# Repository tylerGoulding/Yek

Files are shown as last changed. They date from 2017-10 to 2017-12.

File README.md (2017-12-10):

# YEK
Yek is a prototype of an on-hand password manager that redefines how users interact with account safety and passwords on a laptop computer. It is an embedded device that acts as your personal butler to memorize passwords. With a yek device and a fingerprint scan, you can login to any of your accounts by connecting to any computer device through a bluetooth connection. Yek  acts as a keyboard and types in your login information (username and password) to the selected textbox of a login page, so that you do not have to remember your unique and strong passwords. It can fit in your pocket just like a physical keychain, and yet it can hold 63 of your accounts through a computer application.

## Team
- Fatema Almeshqab
- Tyler Goulding
- Matt Chu

## Code
When prototyping, we developed in Arduino then ported it to AVR C. We have included both for your convenience.

## PCB
The pcb was designed in Eagle. There is one error in the PCB if you are planning to send it out (or printing it in house if that's your slice of pie). The pins on the Battery JST plug are flipped. This is not a major issue but change it if you would like. We did not so that the professors could see our the equivalent PCB we printed.
## Computer Application
The computer application was written in Java and is available as a runnable .jar file that works on Windows, Mac, or Linux, and just requires that Java 8 be installed. The app, uses a library called jSerialComm to communicate with the Yek through a serial port connection.

## Building the Yek
### If you want to use Arduino
To build with Arduino:
Download the following libraries:

U8g2 Screen Library:
> https://github.com/olikraus/U8g2_Arduino

FRAM Library: 

> https://github.com/adafruit/Adafruit_FRAM_I2C

Fingerprint scanner:
> https://github.com/sparkfun/Fingerprint_Scanner-TTL

Bluefruit library:
> https://github.com/adafruit/Adafruit_BluefruitLE_nRF51

Open Arduino and compile the .ino in the folder Yek_arduino

### If you want to use GCC
Use the code in Yek_firmware folder

To build with GCC:

- install avr-gcc (GCC) 7.2.0 using your favorite package manager (this will take 2 hours... sorry)
- download LUFA
- update the path to lufa into makefile
- run make in the folder

## Acknowledgements
* Dean Camera, for LUFA.
* Adafruit (author hathach), for their parts and their BLE library
* Josh Hawley, for his FPS library
* Arduino, for their Print class and Stream class
* Olikraus, for the screen library and compressed fonts
* Zak Kemble, for a AVR implementation of millis
* Mike DiBacco, for helping us lasercut the case
* Some random dude at the Makerspace who helped me 3d print

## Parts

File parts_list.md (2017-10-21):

| Part | Value | Device | Package | Description | PROD_ID | SF_ID | SF_SKU | SKU | VALUE  | |
|---|---|---|---|---|---|---|---|---|---|---|
| C2 | 10uF | 10UF-0603-6.3V-20% | 0603 | 10.0µF ceramic capacitors | CAP-11015  | | | | 10uF | |
| C3 | 22pF | 22PF-0603-50V-5% | 0603 | 22pF ceramic capacitors | CAP-07876  | | | | 22pF | |
| C4 | 22pF | 22PF-0603-50V-5% | 0603 | 22pF ceramic capacitors | CAP-07876  | | | | 22pF | |
| C5 | 1.0uF | 1.0UF-0603-16V-10% | 0603 | 1µF ceramic capacitors | CAP-00868  | | | | 1.0uF  | |
| C6 | 10uF | 10UF-0603-6.3V-20% | 0603 | 10.0µF ceramic capacitors | CAP-11015  | | | | 10uF | |
| C7 | 1.0uF | 1.0UF-0603-16V-10% | 0603 | 1µF ceramic capacitors | CAP-00868  | | | | 1.0uF  | |
| C8 | 10uF | 10UF-0603-6.3V-20% | 0603 | 10.0µF ceramic capacitors | CAP-11015  | | | | 10uF | |
| C9 | 1.0uF | 1.0UF-0603-16V-10% | 0603 | 1µF ceramic capacitors | CAP-00868  | | | | 1.0uF  | |
| CONN | GREEN | LED-GREEN0603 | LED-0603 | Green SMD LED | DIO-00821  | | | | GREEN  | |
| D1 | MBR120 | DIODE_SOD-123FL | SOD-123FL | Diode | | | | | | |
| D4 | Yellow | LED-YELLOW0603 | LED-0603 | Yellow SMD LED | DIO-09003  | | | | Yellow | |
| FRAME1 | FRAME-LEDGER | FRAME-LEDGER | CREATIVE_COMMONS | Schematic Frame - Ledger | | | | | | |
| IC1 | 317EMP | 317EMP | SOT223 | Positive VOLTAGE REGULATOR | | | | | | |
| J1 | | CONN_02JST-PTH-2 | JST-2-PTH | Multi connection point. Often used as Generic Header-pin footprint for 0.1 inch spaced/style header connections | CONN-09863 | | | PRT-09914 | | |
| J2 | FINGER_SCAN | QWIIC_CONNECTORJS-1MM | 1X04_1MM_RA | SparkFun I2C Standard Qwiic Connector | | | | | | |
| J3 | USB_A_PTH_MALE | USB_A_PTH_MALE | USB-A-H | USB-A Connector | CONN-08367 | PRT-00437 | | | | |
| J4 | ISCP | AVR_SPI_PROG_3X2NS | 2X3-NS | AVR ISP 6 Pin | | | | | | |
| JP1 | SCREEN | HEADER-1X6ROUND | 1X06_ROUND | PIN HEADER | | | | | | |
| MODE | RED | LED-RED0603 | LED-0603 | Red SMD LED | DIO-00819  | | | | RED | |
| R6 | 10k | 10KOHM-0603-1/10W-1% | 0603 | 10kΩ resistor | RES-00824  | | | | 10k | |
| R7 | 10k | 10KOHM-0603-1/10W-1% | 0603 | 10kΩ resistor | RES-00824  | | | | 10k | |
| R8 | 10k | 10KOHM-0603-1/10W-1% | 0603 | 10kΩ resistor | RES-00824  | | | | 10k | |
| R9 | 10k | 10KOHM-0603-1/10W-1% | 0603 | 10kΩ resistor | RES-00824  | | | | 10k | |
| R10 | 10k | 10KOHM-0603-1/10W-1% | 0603 | 10kΩ resistor | RES-00824  | | | | 10k | |
| R11 | 10k | 10KOHM-0603-1/10W-1% | 0603 | 10kΩ resistor | RES-00824  | | | | 10k | |
| R12 | 330 | 330OHM-0603-1/10W-1% | 0603 | 330Ω resistor | RES-00818  | | | | 330 | |
| R13 | 330 | 330OHM-0603-1/10W-1% | 0603 | 330Ω resistor | RES-00818  | | | | 330 | |
| R14 | 1k | 1KOHM-0603-1/10W-1% | 0603 | 1kΩ resistor | RES-07856  | | | | 1k | |
| R15 | 10k | 10KOHM-0603-1/10W-1% | 0603 | 10kΩ resistor | RES-00824  | | | | 10k | |
| RST | SPST | MOMENTARY-SWITCH-SPST-SMD-4.5MM | TACTILE_SWITCH_SMD_4.5MM | Momentary Switch (Pushbutton) - SPST | SWCH-09213 | | | | | |
| R_D+ | 22 | 22OHM-0603-1/10W-1% | 0603 | 22Ω resistor | RES-08698  | | | | 22 | |
| R_D- | 22 | 22OHM-0603-1/10W-1% | 0603 | 22Ω resistor | RES-08698  | | | | 22 | |
| S1 | JOYSTICK | JOYSTICK_MINI | JOYSTICK_MINI | Small Tactile Joystick w/ Select Switch | SWCH-09905 | | COM-10063 | | | |
| U$1 | 32U4 | ATMEGA32U4-AU | TQFP44 | http://www.ladyada.net/library/eagle | | | | | | |
| U$3 | FRAM | FRAM | SOIC8 | | | | | | | |
| U2 | MCP73831 | MCP73831 | SOT23-5 | MCP73831T Li-Ion, Li-Pol Controller | IC-09995 | | | | | |
| U3 | nRF51 | NRF51822_MODULE_MDBT40 | BLE_MODULE_RAYTAC_MDBT40 | nRF51822 Bluetooth Low Energy Module | | | | | | |
| Y2 | 16MHz | CRYSTAL-16MHZSMD-5X3.2 | CRYSTAL-SMD-5X3.2-4PAD | 16MHz Crystal | XTAL-08218 | COM-00094 | | | 16MHz  | |

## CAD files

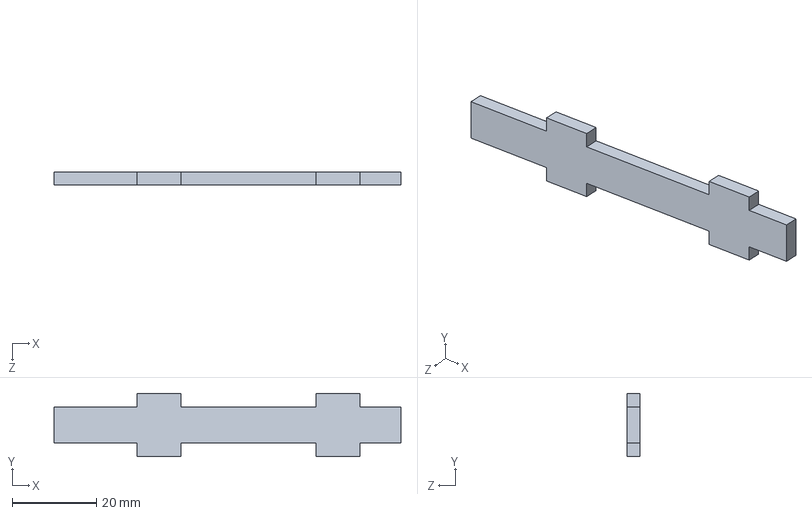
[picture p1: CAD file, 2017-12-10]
Case DXF Files/Side 1 (Gold).SLDPRT
82.5 x 15.0 x 3.17 mm

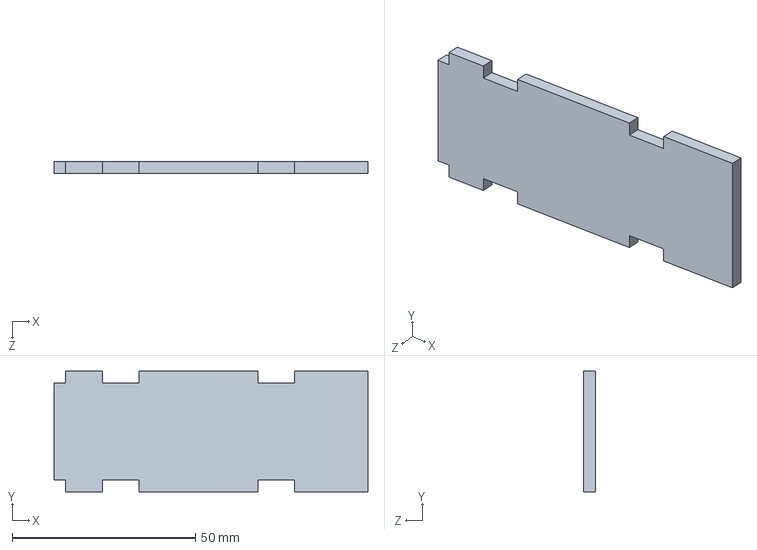
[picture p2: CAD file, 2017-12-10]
Case DXF Files/Baseplate2 (Purple).SLDPRT
85.7 x 32.9 x 3.17 mm

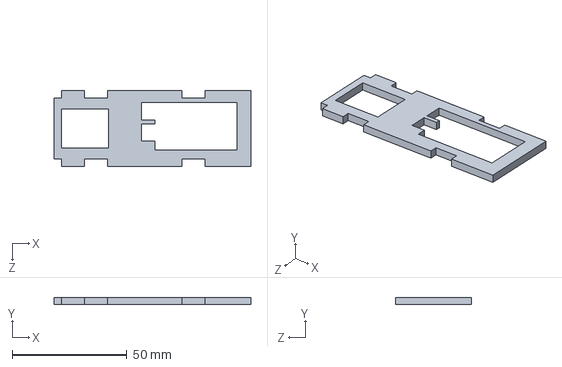
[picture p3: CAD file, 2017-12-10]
Case DXF Files/Topplate2 (Purple).SLDPRT
85.7 x 3.17 x 32.9 mm

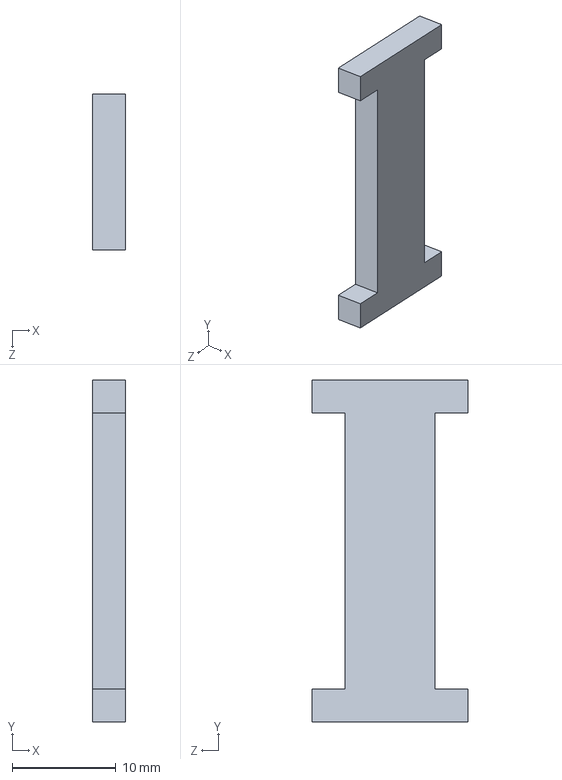
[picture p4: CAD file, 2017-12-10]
Case DXF Files/Back 1 (Gold).SLDPRT
3.17 x 32.9 x 15.0 mm

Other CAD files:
Case DXF Files/Side 2 (Gold).SLDPRT
Case DXF Files/Back 1 (Gold).DXF
Case DXF Files/Baseplate2 (Purple).DXF
Case DXF Files/Side 1 (Gold).DXF
Case DXF Files/Side 2 (Gold).DXF
Case DXF Files/Topplate2 (Purple).DXF

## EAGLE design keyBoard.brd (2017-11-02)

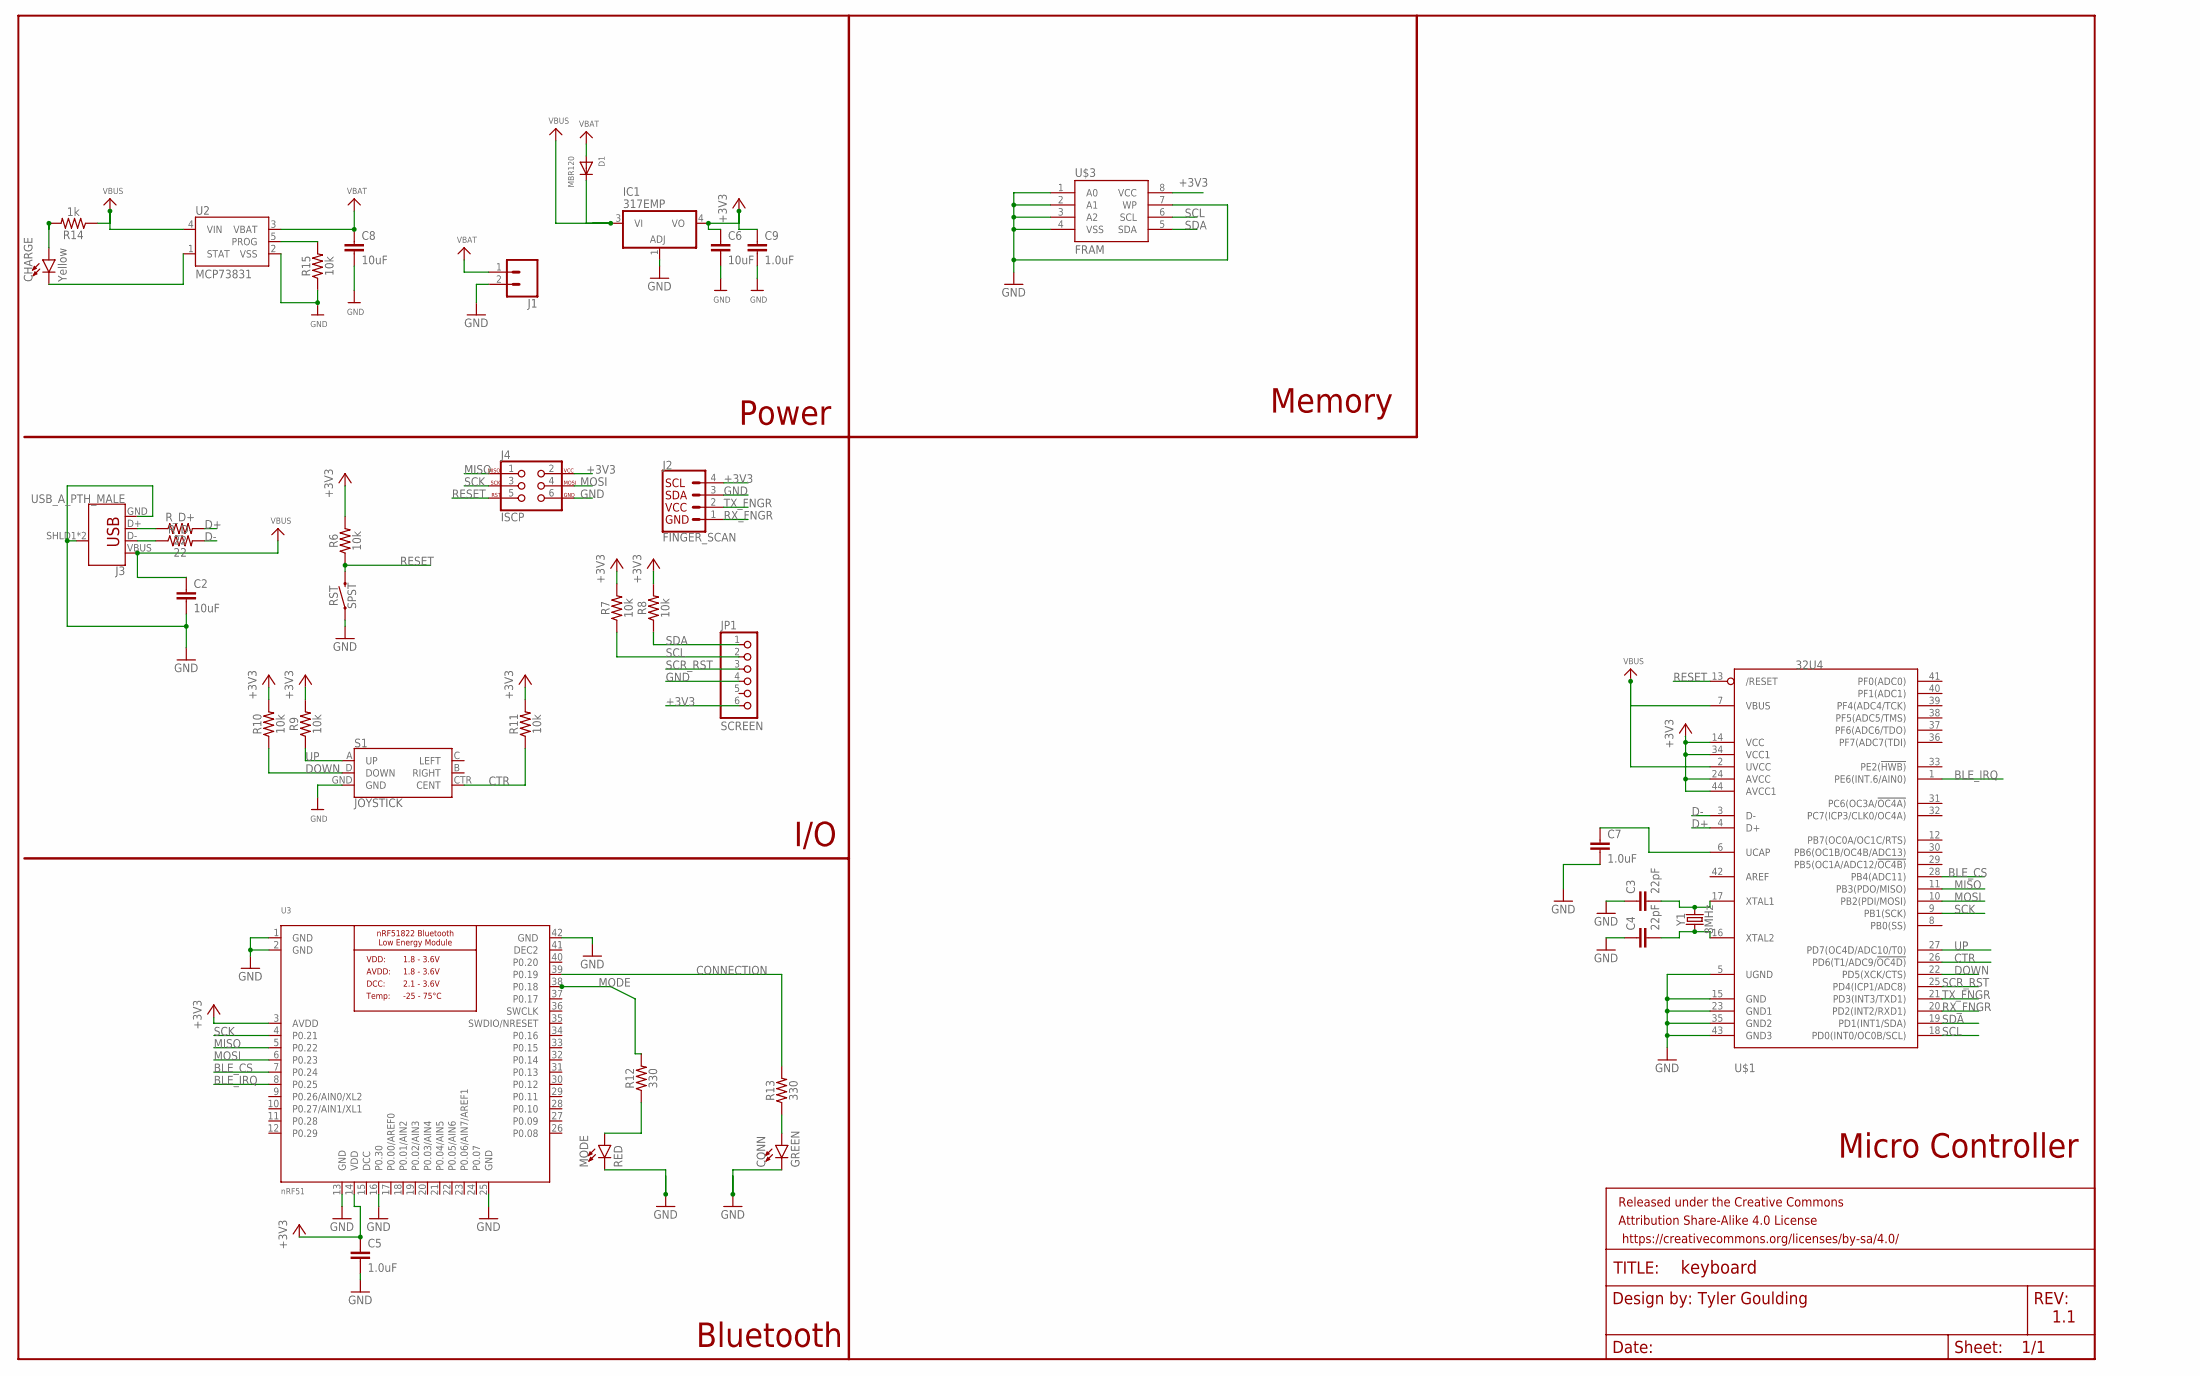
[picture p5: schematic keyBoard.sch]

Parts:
C2, C6, C8: 10uF; 0603
C3, C4: 22pF; 0603
C5, C7, C9: 1.0uF; 0603
CHARGE: Yellow; LED-0603
CONN: GREEN; LED-0603
D1: MBR120; SOD-123FL
FRAME1: FRAME-LEDGER; CREATIVE_COMMONS
IC1: 317EMP; SOT223
J1: CONN_02JST-PTH-2; JST-2-PTH
J2: FINGER_SCAN; 1X04_1MM_RA
J3: USB_A_PTH_MALE; USB-A-H
J4: ISCP; 2X3-NS
JP1: SCREEN; 1X06_ROUND
MODE: RED; LED-0603
R6, R7, R8, R9, R10, R11, R15: 10k; 0603
R12, R13: 330; 0603
R14: 1k; 0603
RST: SPST; TACTILE_SWITCH_SMD_4.5MM
R_D+: 22; 0603
R_D-: 22; 0603
S1: JOYSTICK; JOYSTICK_MINI
U2: MCP73831; SOT23-5
U3: nRF51; BLE_MODULE_RAYTAC_MDBT40
U$1: 32U4; TQFP44
U$3: FRAM; SOIC8
Y1: 8MHz; CRYSTAL-SMD-5X3.2-4PAD

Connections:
+3V3: C5.1, C6.1, C9.1, IC1.4 (VO), J2.4 (SCL), J4.2, JP1.6, R6.2, R7.2, R8.2, R9.2, R10.2, R11.2, U3.3 (AVDD), U3.14 (VDD), U$1.14 (VCC), U$1.24 (AVCC), U$1.34 (VCC1), U$1.44 (AVCC1), U$3.8 (VCC)
BLE_CS: U3.7 (P0.24), U$1.28 (PB4(ADC11))
BLE_IRQ: U3.8 (P0.25), U$1.1 (PE6(INT.6/AIN0))
CONNECTION: R13.2, U3.39 (P0.19)
CTR: R11.1, S1.CTR (CENT), U$1.26 (PD6(T1/ADC9/!OC4D))
D+: R_D+.2, U$1.4 (D+)
D-: R_D-.2, U$1.3 (D-)
DCC: U3.15 (DCC)
DEC2: U3.41 (DEC2)
DOWN: R10.1, S1.D (DOWN), U$1.22 (PD5(XCK/CTS))
GND: C2.2, C3.1, C4.1, C5.2, C6.2, C7.2, C8.2, C9.2, CONN.C, IC1.1 (ADJ), J1.2, J2.3 (SDA), J3.GND, J3.SHLD1 (SHIELD), J3.SHLD2 (SHIELD), J4.6, JP1.4, MODE.C, R15.1, RST.2 (1), RST.3 (1), S1.GND, U2.2 (VSS), U3.1 (GND), U3.2 (GND), U3.13 (GND), U3.16 (P0.30), U3.25 (GND), U3.42 (GND), U$1.5 (UGND), U$1.15 (GND), U$1.23 (GND1), U$1.35 (GND2), U$1.43 (GND3), U$3.1 (A0), U$3.2 (A1), U$3.3 (A2), U$3.4 (VSS), U$3.7 (WP)
MISO: J4.1, U3.5 (P0.22), U$1.11 (PB3(PDO/MISO))
MODE: R12.2, U3.38 (P0.18)
MOSI: J4.4, U3.6 (P0.23), U$1.10 (PB2(PDI/MOSI))
unnamed: CHARGE.A, R14.2
unnamed: J3.D+, R_D+.1
unnamed: J3.D-, R_D-.1
unnamed: MODE.A, R12.1
unnamed: R15.2, U2.5 (PROG)
unnamed: CONN.A, R13.1
RESET: J4.5, R6.1, RST.1 (2), RST.4 (2), U$1.13 (/RESET)
RX_FNGR: J2.1 (GND), U$1.20 (PD2(INT2/RXD1))
SCK: J4.3, U3.4 (P0.21), U$1.9 (PB1(SCK))
SCL: JP1.2, R7.1, U$1.18 (PD0(INT0/OC0B/SCL)), U$3.6 (SCL)
SCR_RST: JP1.3, U$1.25 (PD4(ICP1/ADC8))
SDA: JP1.1, R8.1, U$1.19 (PD1(INT1/SDA)), U$3.5 (SDA)
STAT: CHARGE.C, U2.1 (STAT)
TX_FNGR: J2.2 (VCC), U$1.21 (PD3(INT3/TXD1))
UCAP: C7.1, U$1.6 (UCAP)
UP: R9.1, S1.A (UP), U$1.27 (PD7(OC4D/ADC10/T0))
VBAT: C8.1, D1.A, J1.1, U2.3 (VBAT)
VBUS: C2.1, D1.C, IC1.3 (VI), J3.VBUS, R14.1, U2.4 (VIN), U$1.2 (UVCC), U$1.7 (VBUS)
XTAL1: C3.2, U$1.17 (XTAL1), Y1.3 (2)
XTAL2: C4.2, U$1.16 (XTAL2), Y1.1

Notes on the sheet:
Power
Bluetooth
I/O
Memory
Micro Controller
Tyler Goulding
1.1

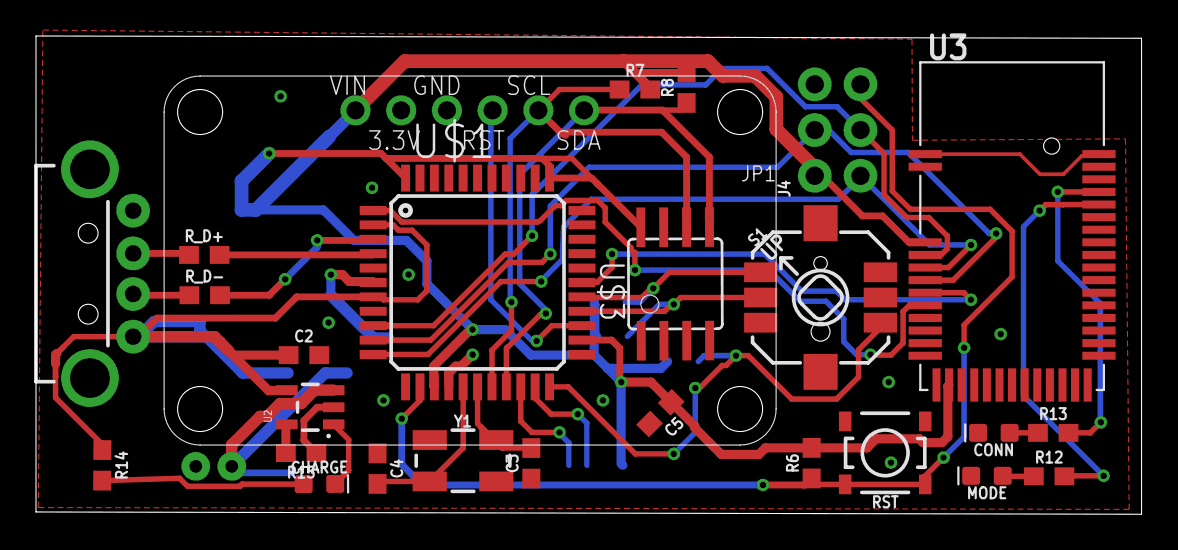
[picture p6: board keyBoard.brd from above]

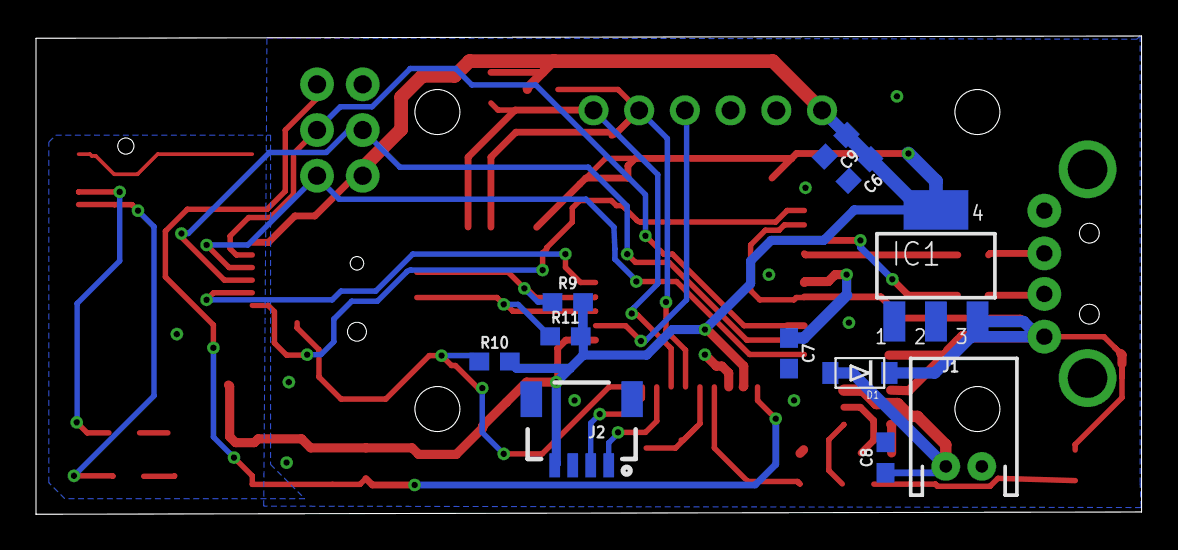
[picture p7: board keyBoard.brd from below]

Board: 2 copper layers, 61.4 x 26.6 mm, 38 parts (11 on the bottom side), 32 nets.

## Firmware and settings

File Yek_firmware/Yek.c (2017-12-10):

/*

        Yek: Password Manager
        18-500 ECE Capstone
        Tyler Goulding, Fatema Almeshqab, Matthew Chu

  This is the main source file for Yek. This file contains the main tasks of
  the demo and is responsible for the initial application hardware configuration.

  We relied heavily on LUFA CDC example for our USB stack. 

  Alot of the libraries used were intended for Arduino so while they are all still
  the code of the respective owners, we had to refactor alot of the function calls.


  Yek stores an offboard non-volatile memory and relays them via BLE to a users computer.


  
  We need to include the below copyright for using the LUFA library.

  We would also like to thank: Adafruit (author hathach), for their parts and their BLE library
                               Josh Hawley, for his FPS library
                               Arduino, for their Print class and Stream class
                               Olikraus, for the screen library and compressed fonts
                               Zak Kemble, for a AVR implementation of millis


*/



// u8x8 COPYRIGHT
/*
Copyright (c) 2016, olikraus@gmail.com
All rights reserved.
*/

// LUFA COPYRIGHT
/*
             LUFA Library
     Copyright (C) Dean Camera, 2017.

  dean [at] fourwalledcubicle [dot] com
           www.lufa-lib.org
*/

/** \file
 *
 *  Main source file for the Yek. This file contains the main tasks of
 *  the demo and is responsible for the initial application hardware configuration.
 */

#include "Yek.h"

/** LUFA CDC Class driver interface configuration and state information. This structure is
 *  passed to all CDC Class driver functions, so that multiple instances of the same class
 *  within a device can be differentiated from one another.
 */
			USB_ClassInfo_CDC_Device_t VirtualSerial_CDC_Interface =
				{
					.Config =
						{
							.ControlInterfaceNumber   = INTERFACE_ID_CDC_CCI,
							.DataINEndpoint           =
								{
									.Address          = CDC_TX_EPADDR,
									.Size             = CDC_TXRX_EPSIZE,
									.Banks            = 1,
								},
							.DataOUTEndpoint =
								{
									.Address          = CDC_RX_EPADDR,
									.Size             = CDC_TXRX_EPSIZE,
									.Banks            = 1,
								},
							.NotificationEndpoint =
								{
									.Address          = CDC_NOTIFICATION_EPADDR,
									.Size             = CDC_NOTIFICATION_EPSIZE,
									.Banks            = 1,
								},
						},
				};

/** Standard file stream for the CDC interface when set up, so that the virtual CDC COM port can be
 *  used like any regular character stream in the C APIs.
 */
static FILE USBSerialStream;
// U8X8_SSD1306_128X32_UNIVISION_HW_I2C u8x8(OLED_RESET);
u8x8_t u8x8;
/* define our globals */
char account_format = TAB_F;
uint16_t framAddr = 0;
/* initialize values for our accounts */
uint8_t total_accounts = 0; /* number of accounts*/
uint8_t c_account = 0;
uint8_t o_account = 0;
uint8_t value;
uint8_t i;
uint8_t iByte;
char keys[BUFSIZE];
uint8_t mode = RUN;
char type [BUFSIZE];
char acc_name [BUFSIZE];
char acc_pass [BUFSIZE];
uint16_t memLoc = 0;

/* button macros */
int state_center_curr;            
int state_center_prev = 1;  
int state_up_curr;            
int state_up_prev = 1;
int state_down_curr;            
int state_down_prev = 1;  
int state_center_temp;
int state_down_temp;
int state_up_temp;

unsigned int debounce_delay = 50;
unsigned int debounce_time_center = 0;  
unsigned int debounce_time_up = 0;  
unsigned int debounce_time_down = 0;  
uint8_t flipState = 0;
uint8_t buttonState;

/** Main program entry point. This routine contains the overall program flow, including initial
 *  setup of all components and the main program loop.
 */
int main(void)
{
	SetupHardware();
	/* Create a regular character stream for the interface so that it can be used with the stdio.h functions */
	CDC_Device_CreateStream(&VirtualSerial_CDC_Interface, &USBSerialStream);
	GlobalInterruptEnable();
	for (;;)
	{
		buttonState = process_buttons();
		if (buttonState == CENTER_LONG_PRESSED) {
			if (mode == UPLOAD) {
			  c_account = 0;  
			  total_accounts = fram_read8(0x0);
			  populateArrays(c_account);
			  updateScreen();
			  mode = RUN;
			  break;
			}
			else if (mode == RUN){
			  mode = UPLOAD;
			  u8x8_ClearDisplay(&u8x8);
			  u8x8_DrawString(&u8x8, 0, 0, "Switch to UPLOAD");
			  break;
			}
		}
	switch(mode) {
	    case UPLOAD:   
	      iByte = -1;
    		if (CDC_Device_BytesReceived(&VirtualSerial_CDC_Interface) > 0) {
	        iByte = CDC_Device_ReceiveByte(&VirtualSerial_CDC_Interface);
	      }
	      switch(iByte)
      	{
        case '0': /* add account */
          u8x8_ClearDisplay(&u8x8);
          u8x8_DrawString(&u8x8, 4, 1, "ADD ACC");   
          addAccount();
          u8x8_ClearDisplay(&u8x8);
          u8x8_DrawString(&u8x8, 4, 1, "Edit Info");
          break;
        case '1': /* remove account */
          u8x8_ClearDisplay(&u8x8);
          u8x8_DrawString(&u8x8, 4, 1, "REM ACC"); 
          removeAccount();
          u8x8_ClearDisplay(&u8x8);
          u8x8_DrawString(&u8x8, 4, 1, "Edit Info");
          break;
        case '2': /* add fingerprint */
          u8x8_ClearDisplay(&u8x8);
          u8x8_DrawString(&u8x8, 4, 1, "ADD FIN");   
          Enroll();
          u8x8_ClearDisplay(&u8x8);
          u8x8_DrawString(&u8x8, 4, 1, "Edit Info");
          break;
        case '3': /* delete All fingerprint */
          u8x8_ClearDisplay(&u8x8);
          u8x8_DrawString(&u8x8, 4, 1, "REM FIN");   
          fps_DeleteAll();
          u8x8_ClearDisplay(&u8x8);
          u8x8_DrawString(&u8x8, 4, 1, "Edit Info");
          break;
        case '4':
          flipState = ~(flipState);
          u8x8_SetFlipMode(&u8x8, flipState);
          u8x8_ClearDisplay(&u8x8);
          u8x8_DrawString(&u8x8, 4, 1, "Edit Info");
        default:
          break;
      }
      break;
	    case RUN:
	      if  (buttonState == UP_PRESSED) { /* (curr_up == LOW) && (old_up == HIGH) */
	        c_account = (c_account + 1) % total_accounts;
	        Delay_MS(25);
	      }
	      else if (buttonState == DOWN_PRESSED) { /* (curr_down == 0) && (old_down != 0) */
	        if (c_account == 0){
	          c_account = total_accounts-1;
	        }
	        else{
	          c_account = (c_account - 1) % total_accounts;
	        }
	        Delay_MS(25);
	      }
	      else if  (buttonState == CENTER_SHORT_PRESSED) {
	        fps_SetLED(true);
	        u8x8_ClearDisplay(&u8x8);
	        u8x8_DrawString(&u8x8, 4, 1, "Press Finger");        
	        /* Time out loop... */
	        uint8_t badCount = 0;
	        for (int count = 0; count < 150; count++) {
	          if (fps_IsPressFinger()) {
	            fps_CaptureFinger(false);
	            uint8_t id = fps_Identify1_N();
	            if (id < 200)
	            {
	              ble_print("AT+BleKeyboard=");
	              ble_println_array(acc_name); /*keys*/
	              Delay_MS(200);
	              ble_print("AT+BleKeyboard=");
	              ble_println_str("\t");
	              ble_waitForOK();
	              ble_print("AT+BleKeyboard=");
	              ble_println_array(acc_pass); /*keys*/
	              ble_waitForOK();
	              ble_print("AT+BleKeyboard=");
	              ble_println_str("\\n\n\\r\n\n"); /*keys*/
	              break;
	            } 
	            else { //if unable to recognize
	              badCount++;
	              if (badCount > 10) {
	                break;
	              }
	            }         
	          }
	        }
	      fps_SetLED(false);
	      updateScreen();
	      }
	      break;
	    default:
	      /* how are you here?     */
	      /* Congrat you broke it. */
	      break;
	  }
		/* Must throw away unused bytes from the host, or it will lock up while waiting for the device */
		CDC_Device_ReceiveByte(&VirtualSerial_CDC_Interface);
		CDC_Device_USBTask(&VirtualSerial_CDC_Interface);
		USB_USBTask();
	}
}

/** Configures the board hardware and chip peripherals for the demo's functionality. */
void SetupHardware(void)
{
	/* Disable watchdog if enabled by bootloader/fuses */
	MCUSR &= ~(1 << WDRF);
	wdt_disable();
	/* Disable clock division */
	clock_prescale_set(clock_div_1);

	/* Hardware Initialization */
	millis_init();
	Buttons_Init();
	setupScreen();
	fram_begin();
	/* grab the total number of account stored in the system */
	total_accounts = fram_read8(0x0);
  fps_New();
	fps_Open();         //send serial command to initialize fps
	setupBLE();
	USB_Init();
}
uint8_t u8x8_hw_i2c(U8X8_UNUSED u8x8_t *u8x8, U8X8_UNUSED uint8_t msg, U8X8_UNUSED uint8_t arg_int, U8X8_UNUSED void *arg_ptr)
{
#ifdef U8X8_HAVE_HW_I2C
  switch(msg)
  {
    case U8X8_MSG_BYTE_SEND:
      TWI_SendByte((uint8_t)*data);  
      break;
    case U8X8_MSG_BYTE_INIT:
      TWI_Init(TWI_BIT_PRESCALE_1, TWI_BITLENGTH_FROM_FREQ(1, 100000));
      break;
    case U8X8_MSG_BYTE_SET_DC:
      break;
    case U8X8_MSG_BYTE_START_TRANSFER:
      TWI_StartTransmission (0x3C, 10);
      break;
    case U8X8_MSG_BYTE_END_TRANSFER:
      TWI_StopTransmission();
      break;
    default:
      return 0;
  }
#endif
  return 1;
}
uint8_t u8x8_no_CB(U8X8_UNUSED u8x8_t *u8x8, U8X8_UNUSED uint8_t msg, U8X8_UNUSED uint8_t arg_int, U8X8_UNUSED void *arg_ptr)
{
  /* the dummy callback will not handle any message and will fail for all messages */
  return 0;
}

void setupScreen() {
  u8x8_Setup(&u8x8, u8x8_d_ssd1306_128x32_univision, u8x8_cad_ssd13xx_i2c, u8x8_hw_i2c, u8x8_no_CB);
  u8x8_InitDisplay(&u8x8);
  u8x8_SetPowerSave(&u8x8, 0);
  u8x8_SetFont(&u8x8,u8x8_font_chroma48medium8_r);
  u8x8_DrawString(&u8x8, 0, 0, "Yek");
  u8x8_DrawString(&u8x8, 0, 1, "18500");
  u8x8_DrawString(&u8x8, 0, 2, "Fatema, Matt,");
  u8x8_DrawString(&u8x8, 0, 3, "and Tyler");
}
void setupBLE() {
  ble_New();

  ble_begin(VERBOSE_MODE);
  if ( FACTORYRESET_ENABLE )
  {
    /* Perform a factory reset to make sure everything is in a known state */
    if ( ! ble_factoryReset() ){
    }
  }
  ble_echo(false);
  ble_setName();
  if (ble_isVersionAtLeast() )
  {
    if ( !ble_setHIDEn()) {
    }
  }else
  {
    if (! ble_setKeyboardOn()) {
    }
  }
  ble_reset();
}

void populateArrays(uint8_t accountNum) {
  memset(type,0,BUFSIZE);
  memset(acc_name,0,BUFSIZE);
  memset(acc_pass,0,BUFSIZE);

  memLoc = (accountNum+1)*512;
  account_format = fram_read8(memLoc);
  // Serial.println(account_format);
  for (i = 1; i < BUFSIZE; i++) {
      framAddr = memLoc + i;
      value = fram_read8(framAddr);
      if (value == '+'){
        break;
      }
      type[i-1] = value;
      
  }
  for (i = 0; i < BUFSIZE; i++) {
      framAddr = memLoc + i + BUFSIZE;
      value = fram_read8(framAddr);
      if (value == '+'){
        break;
      }
      acc_name[i] = value;
  }
  for (i = 0; i < BUFSIZE; i++) {
      framAddr = memLoc + i+ (2*BUFSIZE);
      value = fram_read8(framAddr);
      if (value == '+'){
        break;
      }
      acc_pass[i] = value;
  }  
}

uint8_t process_buttons(void) {

  uint8_t button_case = NONE_PRESSED; 
  //up 
  
  state_up_temp = !(PIND == 0b1111111); 
  if (state_up_temp != state_up_prev) {
    // reset the debouncing timer
    debounce_time_up = millis();
  }

  if ((millis() - debounce_time_up) > debounce_delay) {
    if ((state_up_curr != state_up_temp)) {
      state_up_curr = state_up_temp;
      if (state_up_curr == LOW) {
        button_case = UP_PRESSED;
      }
    }
  }
  state_up_prev = state_up_temp;
  //center 
  state_center_temp = !(PIND == 0b10111111); 
  
   if (state_center_temp != (state_center_prev)) {
    // reset the debouncing timer
    debounce_time_center = millis();
  }

  if ((millis() - debounce_time_center) > debounce_delay) {
    if ((state_center_curr != state_center_temp)) {
      state_center_curr = state_center_temp;

      int count = 0;
      if (state_center_curr == LOW) {
        while (state_center_curr == !(PIND == 0b10111111)) {
          Delay_MS(10);
          count++;
        }

        if (count > 100) {
          button_case = CENTER_LONG_PRESSED;
        }

        else { 
          button_case = CENTER_SHORT_PRESSED;
        }
      }
    }
  }
  state_center_prev = state_center_temp;
  //down
  state_down_temp = !(PIND == 0b11011111); 
  
   if (state_down_temp != state_down_prev) {
    // reset the debouncing timer
    debounce_time_down = millis();
  }


  if ((millis() - debounce_time_down) > debounce_delay) {
    if ((state_down_curr != state_down_temp)) {
      state_down_curr = state_down_temp;

      if (state_down_curr == LOW) {
        button_case = DOWN_PRESSED;
      }
    }
  }
  
  state_down_prev = state_down_temp;
  
  return button_case;
}

void addAccount() {
  memset(keys,0,BUFSIZE);
  /* Wait till there is some data on the line */
  fread(keys, BUFSIZE,1,&USBSerialStream);
  /* update total account and store in memory */
  total_accounts = (total_accounts + 1)%64;
  fram_write8(0x0, total_accounts); 
  u8x8_ClearDisplay(&u8x8);
  u8x8_DrawString(&u8x8, 0, 0,"Type Rec.");
  Delay_MS(200);
  for (i = 0; i<BUFSIZE; i++) {
    fram_write8((total_accounts)*512+i, keys[i]);
  }
  memset(keys,0,BUFSIZE);
  fread(keys, BUFSIZE,1,&USBSerialStream);
  u8x8_ClearDisplay(&u8x8);
  u8x8_DrawString(&u8x8, 0, 0,"Name Rec.");
    Delay_MS(200);

  for (i = 0; i<BUFSIZE; i++) {
    fram_write8((total_accounts)*512+i+128, keys[i]);
  }
  memset(keys,0,BUFSIZE);
  fread(keys, BUFSIZE,1,&USBSerialStream);

  u8x8_ClearDisplay(&u8x8);
  u8x8_DrawString(&u8x8, 0, 0,"Pass Rec.");
  Delay_MS(200);

  /* send password last - load into third 128 bytes of mem segment*/
  for (i = 0; i<BUFSIZE; i++) {
    fram_write8((total_accounts)*512+i+256, keys[i]);
  }  
}

void removeAccount(){
  /* clear the buffer for good luck */
  memset(keys,0,BUFSIZE);

  /* this is non-blocking but we never had an issue */  
  fread(keys, BUFSIZE,1,&USBSerialStream);

  i = 0;
  uint8_t j = 0;
  /* search all account for a match */
  while (i < total_accounts) {
    memset(type,0,BUFSIZE);
    memLoc = (i+1)*512;
    /* populate type array */
    for (j = 1; j < BUFSIZE; j++) {
        framAddr = memLoc + j;
        value = fram_read8(framAddr);
        if (value == '+'){
          break;
        }
        type[j-1] = value;
    }
    /* check if names are the same */
    if (compareArray(type,keys)) {
      /* delete the account */
      value = deleteAcc(i);
      }
    i++;
  }
}

/*
 * deleteAcc(a) -> deletes the a'th account and move up the last account
 *
 */
int deleteAcc(uint8_t a){
  memLoc = (a+1)*512;
  for (uint16_t z = 0; z < 512; z++) {
    fram_write8(memLoc + z,0);
  }
  /* lower total account and save to memory */
  total_accounts -= 1;
  fram_write8(0x0, total_accounts);
  /* we are deleting the last account so we are done */
  if (a == (total_accounts)){
    return 1;
  }
  /* we are not deleting the last account */
  else{ 
    /* grab the data from the current last account */
    populateArrays(total_accounts);
    memLoc = (a+1)*512;
    uint16_t tLoc = (total_accounts+1)*512;
    /* copy it into the recently cleared account 
     * This causes a change in order but prevents fragmentation
     */
    fram_write8(memLoc,tLoc);    
    for (i = 1; i < BUFSIZE; i++) {
        framAddr = memLoc + i;
        fram_write8(framAddr,type[i-1]);
    }
    for (i = 0; i < BUFSIZE; i++) {
        framAddr = memLoc + i;
        value = fram_read8(framAddr);
    }    
    for (i = 0; i < BUFSIZE; i++) {
        framAddr = memLoc + i + BUFSIZE;
        fram_write8(framAddr,acc_name[i]);
    }
    for (i = 0; i < BUFSIZE; i++) {
        framAddr = memLoc + i+ (2*BUFSIZE);
        fram_write8(framAddr,acc_pass[i]);
    } 
    return 0; 
  }
}


/*
 * compareArray(a,b) -> returns 1 if same, return 0 if different
 *
 */
int compareArray(char* a, char* b){
    for (uint8_t j = 0; j < BUFSIZE; j++) {
      if (a[j] != b[j]){
        return 0;
      }
    }
    return 1;  
}


void Enroll() {
  fps_SetLED(true);

  u8x8_ClearDisplay(&u8x8);
  
  // find open enroll id
  int enrollid = 0;
  bool usedid = true;
  while (usedid == true)
  {
    usedid = fps_CheckEnrolled(enrollid);
    if (usedid == true) enrollid++;
  }
  fps_EnrollStart(enrollid);
  u8x8_DrawString(&u8x8, 0, 1, "Press Finger");
  while (fps_IsPressFinger() == false) Delay_MS(100);
  bool bret = fps_CaptureFinger(true);
  int iret = 0;
  if (bret != false)
  {
    u8x8_ClearDisplay(&u8x8);
    u8x8_DrawString(&u8x8, 0, 1, "Lift Finger");
    fps_Enroll1();
    while (fps_IsPressFinger() == true) Delay_MS(100);
    u8x8_ClearDisplay(&u8x8);
    u8x8_DrawString(&u8x8, 0, 1, "Press Finger");
    while (fps_IsPressFinger() == false) Delay_MS(100);
    bret = fps_CaptureFinger(true);
    if (bret != false)
    {
      u8x8_ClearDisplay(&u8x8);
      u8x8_DrawString(&u8x8, 0, 1, "Lift Finger");
      fps_Enroll2();
      while (fps_IsPressFinger() == true) Delay_MS(100);
      u8x8_ClearDisplay(&u8x8);
      u8x8_DrawString(&u8x8, 0, 1, "Press Finger");
      while (fps_IsPressFinger() == false) Delay_MS(100);
      bret = fps_CaptureFinger(true);
      if (bret != false)
      {
        iret = fps_Enroll3();
        if (iret == 0)
        {
          u8x8_ClearDisplay(&u8x8);
          u8x8_DrawString(&u8x8, 0, 1, "Fingerprint suc-");
          u8x8_DrawString(&u8x8, 0, 2, "cessfully added");
        }
        else
        {
          u8x8_ClearDisplay(&u8x8);
          u8x8_DrawString(&u8x8, 0, 1, "Failed");
        }
      }
      else {
        u8x8_ClearDisplay(&u8x8);
        u8x8_DrawString(&u8x8, 0, 1, "Failed");

      }
    }
    else {
      u8x8_ClearDisplay(&u8x8);
      u8x8_DrawString(&u8x8, 0, 1, "Failed");

    }
  }
  else {
    u8x8_ClearDisplay(&u8x8);
    u8x8_DrawString(&u8x8, 0, 1, "Failed");

  }
  fps_SetLED(false);

}


void updateScreen() {
    u8x8_ClearDisplay(&u8x8);
    if (total_accounts == 0){
      u8x8_DrawString(&u8x8, 0, 1, "No Accounts");
      Delay_MS(25);
      return;
    }
    u8x8_DrawString(&u8x8, 0,0, "Type:");
    u8x8_DrawString(&u8x8, 2, 1, type);
    u8x8_DrawString(&u8x8, 0,2, "Name:");
    u8x8_DrawString(&u8x8, 2, 3, acc_name);
    Delay_MS(25);
}

/** Event handler for the library USB Connection event. */
void EVENT_USB_Device_Connect(void)
{
}

/** Event handler for the library USB Disconnection event. */
void EVENT_USB_Device_Disconnect(void)
{
}

/** Event handler for the library USB Configuration Changed event. */
void EVENT_USB_Device_ConfigurationChanged(void)
{
	bool ConfigSuccess = true;

	ConfigSuccess &= CDC_Device_ConfigureEndpoints(&VirtualSerial_CDC_Interface);

	// LEDs_SetAllLEDs(ConfigSuccess ? LEDMASK_USB_READY : LEDMASK_USB_ERROR);
}

/** Event handler for the library USB Control Request reception event. */
void EVENT_USB_Device_ControlRequest(void)
{
	CDC_Device_ProcessControlRequest(&VirtualSerial_CDC_Interface);
}

/** CDC class driver callback function the processing of changes to the virtual
 *  control lines sent from the host..
 *
 *  \param[in] CDCInterfaceInfo  Pointer to the CDC class interface configuration structure being referenced
 */
void EVENT_CDC_Device_ControLineStateChanged(USB_ClassInfo_CDC_Device_t *const CDCInterfaceInfo)
{
	/* You can get changes to the virtual CDC lines in this callback; a common
	   use-case is to use the Data Terminal Ready (DTR) flag to enable and
	   disable CDC communications in your application when set to avoid the
	   application blocking while waiting for a host to become ready and read
	   in the pending data from the USB endpoints.
	*/
	bool HostReady = (CDCInterfaceInfo->State.ControlLineStates.HostToDevice & CDC_CONTROL_LINE_OUT_DTR) != 0;
  (void) HostReady;
}

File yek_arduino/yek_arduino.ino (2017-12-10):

/*
      YEK - the Password Manager
   By Tyler Goulding and Fatema Almeshqab

   Source for our capstone 18500 undergraduate project

*/
#include <Arduino.h>
#include <Wire.h>
#include "Adafruit_BLE.h"
#include "Adafruit_BluefruitLE_SPI.h"
#include "FPS_GT511C3.h"
#include "Adafruit_FRAM_I2C.h"
#include "yek.h"
#include <U8x8lib.h>

/* these are all of our peripherals */
U8X8_SSD1306_128X32_UNIVISION_HW_I2C u8x8(OLED_RESET);
Adafruit_BluefruitLE_SPI ble(BLUEFRUIT_SPI_CS, BLUEFRUIT_SPI_IRQ, -1);
FPS_GT511C3 fps;
Adafruit_FRAM_I2C fram = Adafruit_FRAM_I2C();

/* define our globals */
char account_format = TAB_F;
uint16_t framAddr = 0;
/* initialize values for our accounts */
uint8_t total_accounts = 0; /* number of accounts*/
uint8_t c_account = 0;
uint8_t o_account = 0;
uint8_t value;
uint8_t i;
uint8_t iByte;
char keys[BUFSIZE];
uint8_t mode = RUN;
char type [BUFSIZE];
char acc_name [BUFSIZE];
char acc_pass [BUFSIZE];
uint16_t memLoc = 0;
/* button macros */
int state_center_curr;            
int state_center_prev = HIGH;  
int state_up_curr;            
int state_up_prev = HIGH;
int state_down_curr;            
int state_down_prev = HIGH;  
int state_center_temp;
int state_down_temp;
int state_up_temp;
uint8_t flipState = 0;
unsigned int debounce_delay = 50;
unsigned int debounce_time_center = 0;  
unsigned int debounce_time_up = 0;  
unsigned int debounce_time_down = 0;  
uint8_t buttonState;

void setup() {
  // put your setup code here, to run once:
  Serial.begin(9600);
  setupScreen();
  fram.begin();
  /* grab the total number of account stored in the system */
//  fram.write8(0,0);
  total_accounts = fram.read8(0x0);
  delay(2000);
  fps.Open();         //send serial command to initialize fps
  setupBLE();
  DDRD &= 0b00011111;
  PORTD |= 0b11100000;
  populateArrays(c_account);
  delay(1500);
  u8x8.setFlipMode(flipState);
  updateScreen();
}

void loop() {
  buttonState = process_buttons();
  if (buttonState == CENTER_LONG_PRESSED) {
    if (mode == UPLOAD) {
      c_account = 0;  
      total_accounts = fram.read8(0x0);
      populateArrays(c_account);
      updateScreen();
      mode = RUN;
      return;
    }
    else if (mode == RUN){
      mode = UPLOAD;
      u8x8.clear();
      u8x8.drawString(4, 1, "Edit Info");
      // Serial.println(total_accounts);
      return;
    }
  }
  switch(mode) {
    case UPLOAD:   
      uint8_t e;
      iByte = -1;
      if (Serial.available() > 0) {
        iByte = Serial.read();
        
      }
      switch(iByte)
      {
        case '0': /* add account */
          u8x8.clear();
          u8x8.drawString(4, 1, "ADD ACC");   

          addAccount();
          u8x8.clear();
          u8x8.drawString(4, 1, "Edit Info");

          break;
        case '1': /* remove account */
          u8x8.clear();
          u8x8.drawString(4, 1, "REM ACC"); 
          removeAccount();
          u8x8.clear();
          u8x8.drawString(4, 1, "Edit Info");
          break;
        case '2': /* add fingerprint */
          u8x8.clear();
          u8x8.drawString(4, 1, "ADD FIN");   
          Enroll();
          u8x8.clear();
          u8x8.drawString(4, 1, "Edit Info");
          break;
        case '3': /* delete All fingerprint */
          u8x8.clear();
          u8x8.drawString(4, 1, "REM FIN");   
//          break; 
//         Serial.println("CANT DELETE, WE DONT HAVE A FPS");
          fps.DeleteAll();
          u8x8.clear();
          u8x8.drawString(4, 1, "Deleted"); 
          delay(500);
          u8x8.clear();
          u8x8.drawString(4, 1, "Edit Info");
          break;
        case '4':
          flipState = ~(flipState);
          u8x8.setFlipMode(flipState);
          u8x8.clear();
          u8x8.drawString(4, 1, "Edit Info");
        default:
          if (iByte != 255){
            // Serial.println(iByte);
          }
          break;
      }
      break;
    case RUN:
      if  (buttonState == UP_PRESSED) { /* (curr_up == LOW) && (old_up == HIGH) */
        c_account = (c_account + 1) % total_accounts;
        delay(50);
      }
      else if (buttonState == DOWN_PRESSED) { /* (curr_down == 0) && (old_down != 0) */
        if (c_account == 0){
          c_account = total_accounts-1;
        }
        else{
          c_account = (c_account - 1) % total_accounts;
        }
        delay(50);
      }
      else if  (buttonState == CENTER_SHORT_PRESSED) {
        
//        return;      
//        delay(100);
        fps.SetLED(true);
        u8x8.clear();
        u8x8.drawString(4, 1, "Press Finger");        
        /* Time out loop... */
        uint8_t badCount = 0;
        
        for (int count = 0; count < 100; count++) {
          if (fps.IsPressFinger()) {
            u8x8.drawString(4, 2, "is Finger");        
  
            fps.CaptureFinger(false);
            byte id = fps.Identify1_N();
            u8x8.drawString(4, 3, id);        

            if (id < 200)
            {
              ble.print("AT+BleKeyboard=");
              ble.println(acc_name); /*keys*/
              ble.waitForOK();
              delay(200);
              if (account_format == ENTER_F) {
                ble.print("AT+BleKeyboard=");
                ble.println("\\n\n\\r\n\n");  
                ble.waitForOK();
                delay(2500);

              } else {
                ble.print("AT+BleKeyboard=");
                ble.println("\\t");  
                ble.waitForOK();
              }
              ble.print("AT+BleKeyboard=");
              ble.println(acc_pass); /*keys*/
              ble.waitForOK();
              ble.print("AT+BleKeyboard=");
              ble.println("\\n\n\\r\n\n"); /*keys*/
              break;
            } 
            else { //if unable to recognize
              badCount++;
              if (badCount > 10) {
                // Serial.println("FAILED");
                break;
              }
            }         
          }
        }
      fps.SetLED(false);
      updateScreen();
      }
      break;
    default:
      /* how are you here?     */
      /* Congrat you broke it. */
      break;
  }
  if (c_account != o_account){
    memLoc = (c_account+1)*512;
    populateArrays(c_account);
    updateScreen();
  }
  o_account = c_account;
}
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

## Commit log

2017-10-11 routing board
    [keyBoard.brd]
2017-10-21 updating board
    [keyBoard.brd, keyBoard.sch]
2017-10-21 editted gitignore & deleted some files
    [keyBoard.brd, keyBoard.sch]
2017-10-21 updated power circuit and layout
2017-10-22 forgot to connect DOWN on the joystick
    [keyBoard.brd, keyBoard.sch]
2017-11-02 final board, mid-semester arduino proof of concept, non-working disjoint AVR C code
    [keyBoard.brd, keyBoard.sch]
2017-12-10 adding all the code and some other stuff
    [Back 1 (Gold).DXF, Back 1 (Gold).SLDPRT, Baseplate2 (Purple).DXF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]

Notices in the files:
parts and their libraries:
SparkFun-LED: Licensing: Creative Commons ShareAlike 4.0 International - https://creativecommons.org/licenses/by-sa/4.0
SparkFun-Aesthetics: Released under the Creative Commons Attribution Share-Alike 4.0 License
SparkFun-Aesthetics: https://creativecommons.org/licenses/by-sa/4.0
